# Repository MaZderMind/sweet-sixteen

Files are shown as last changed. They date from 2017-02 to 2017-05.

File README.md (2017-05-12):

# Sweet Sixteen
> a 16x2 Characters Sixten-Segment, RaspberryPi driven Display

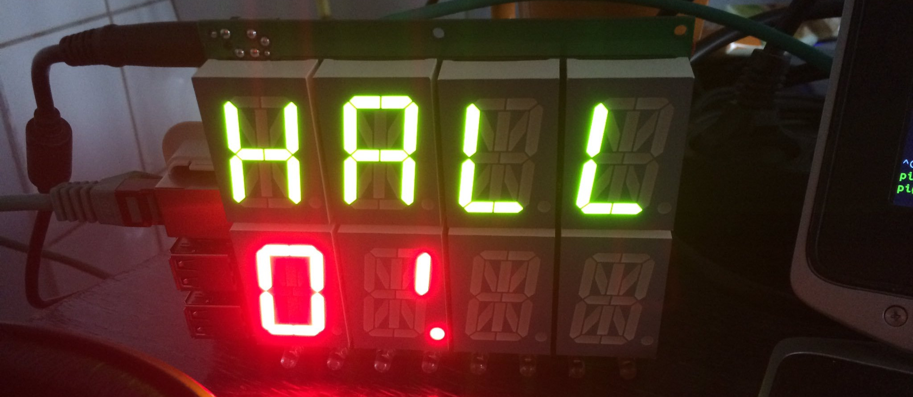
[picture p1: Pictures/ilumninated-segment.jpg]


## Quick Links
 * <a href="Hardware/Schematic.pdf">Schematic (PDF)</a>
 * <a href="Hardware/PCB-Layout.png">PCB Layout (Image)</a>
 * <a href="Hardware/BOM.ods">BOM</a>
 * <a href="Datasheets/">Datasheets</a>
 * <a href="https://github.com/MaZderMind/sweet-sixteen-scheduler">Software</a>

## System Design

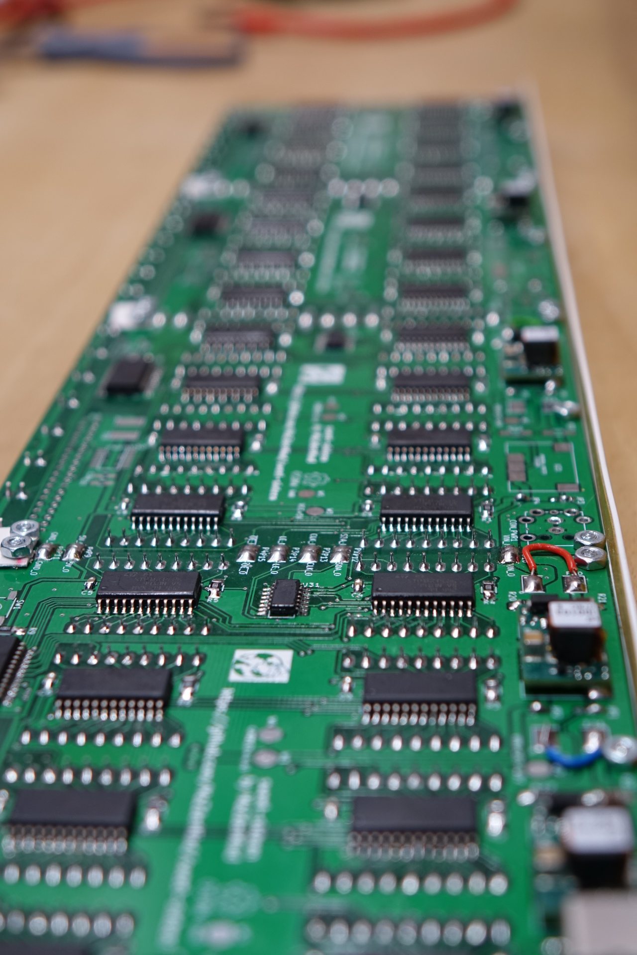
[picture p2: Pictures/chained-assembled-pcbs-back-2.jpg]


The System is built around [STP16CPC26](Datasheets/STP16CPC26.pdf) LED-Drivers in a direct drive configuration. Each LED-Driver has 16 Constant-Current sinks, each of which powers one Segment of the [PSA12-11](Datasheets/PSA12_11CGKWA.pdf) 16-Segment Displays.

The PCBs are built to be Chainable. The first Board in the Chain provides Data and the 5V Rail. It also carries the RaspberryPi "Piggy Back". The Board powers the Pi via its GPIO-Header, so there is no need to supply extra Power to the Pi (and you should not do that.)

## Signal Flow

The RaspberryPi generates Clock and Data via its Hardware-SPI Port (GPIO 10 & 11). Additionally it generates a Latch-Signal on GPIO 22 and an inverted Output-Enable Signal, which is can be used to Dim the LED-Drivers down, on one of its Hardware PWM Pins (GPIO 18).

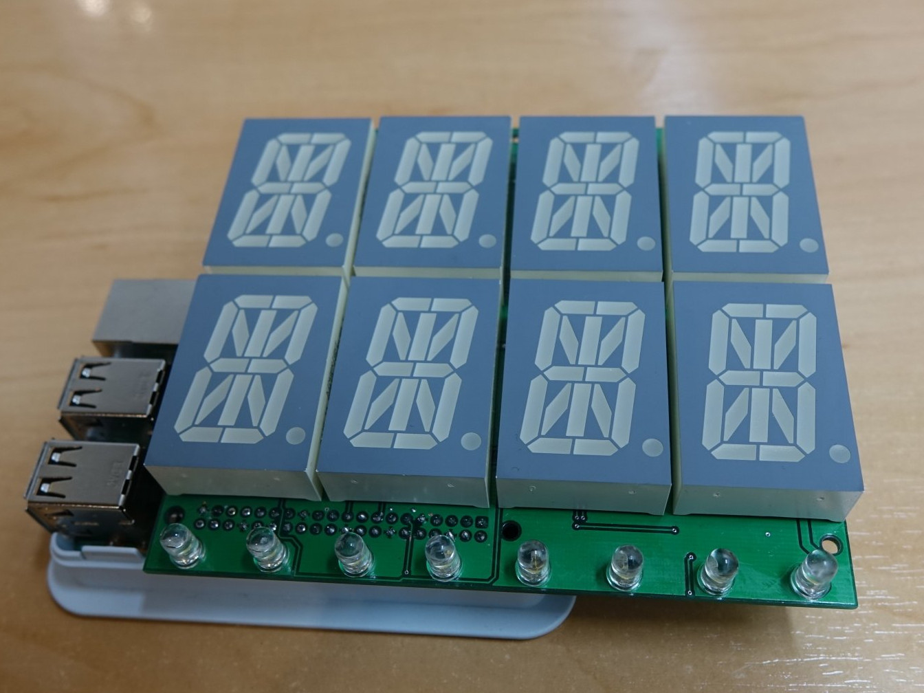
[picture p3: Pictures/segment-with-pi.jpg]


All of these Signals are 3.3V rated. They are directly fed into a [SN74HCT08](Datasheets/sn74hct08.pdf) and-gate which is used to convert the Signals to 5V compatible swing. These Signal then go on a parallel bus to all LED-Drivers (Clock, Latch and Output-Enable) resp. to the first LED-Driver (Data).

The LED-Drivers behave like Shift-Registers on the Data-Side, so the Data-Line ist chained from the input of one LED-Driver to the next, through all 9 Drivers. Drivers 1-8 each control one of the 16 Segments of one of the 8 Digits, while the 9th Driver controls the Decimal Points of all Digits as well as the Row of the 8 LEDs on the bottom of the PCB.

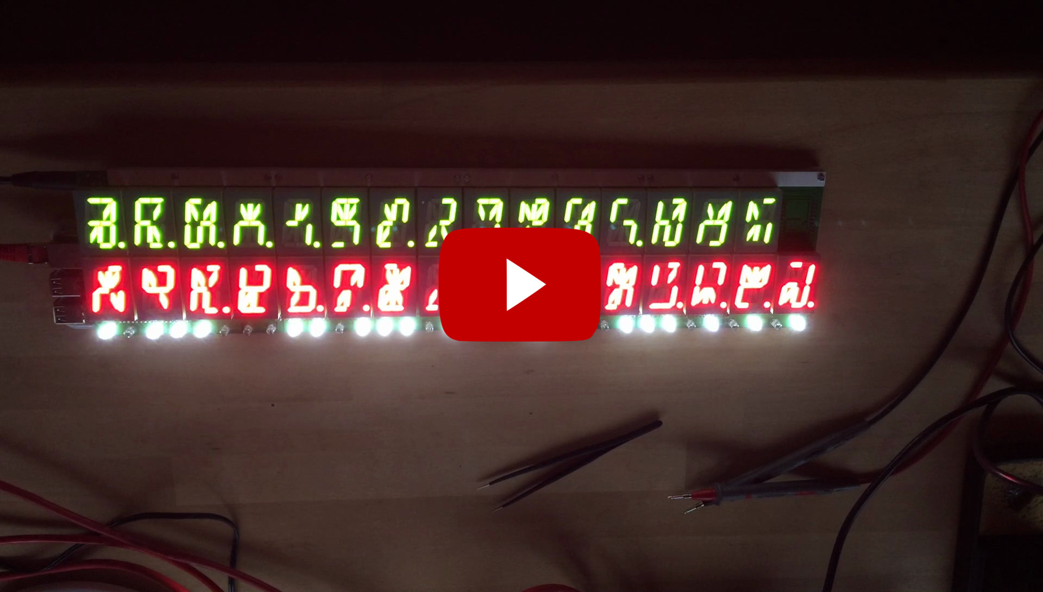
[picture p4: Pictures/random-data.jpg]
4 Boards displaying random Data


The Data-Output of the last LED-Driver as well as the paralleld Bus of Clock, Latch and Output Enable are fed to another [SN74HCT08](Datasheets/sn74hct08.pdf) and-gate which is here used as a line-driver to drive the LED-Drivers on the next PCB. After the and-gate the Signal is routed to Solder-Pads on the edge of the PCB which line up with matching Pads on the opposite Edge of the next PCB.

The Signals coming from those Pads feed into the next 9 LED-Drivers, just as the Raspberry-Pi did on the first PCB. The Components needed to interface to the Raspberry-Pi (Connectors, Fuse, and-Gate and some Caps) are not fitted on the following PCBs.

## Power System

The Whole System is Powered from a Notebook-Plugpack. I chose a Dell 19V/90W Plugpack because they are quite easy to get new or used on ebay for a small amount of money everywhere on the world. I terms of Power per Euro/Dollar Notebook-Chargers are unbeatable.

The 19V (actually the Input-Rail can range from 15V to 40V DC) is fed into two DC-DC Converter Modules on the first PCB, each of which is capable of generating up to 3A.

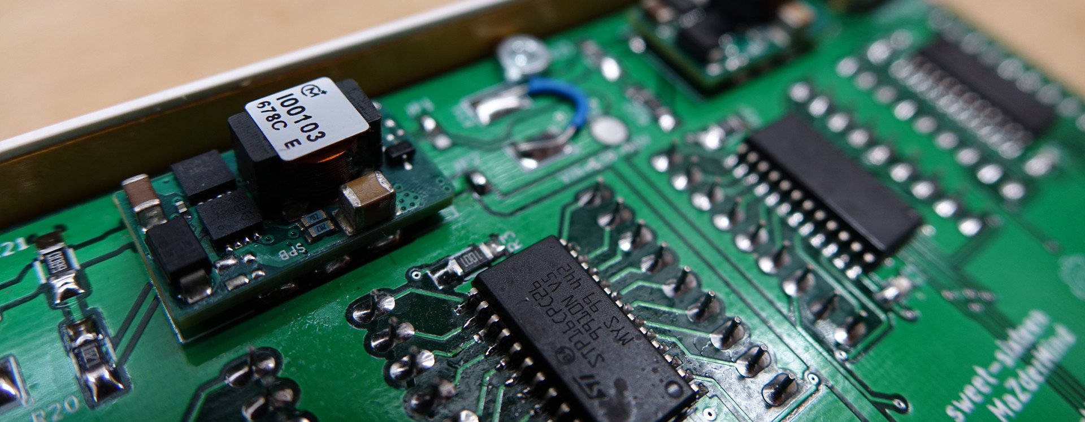
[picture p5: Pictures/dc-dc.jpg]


The first DC-DC Converter generates 5V and powers the RaspberryPi as well as as all the Logic-ICs on all PCBs.
The second Converter generates a 4.4V rail used to Power the LEDs – but this time only on the first PCB.

The following PCBs accept the 5V VCC Rail generated on the first PCB as well as the input-voltage from the Plugpack, also via Pads on the Edge of the PCBs. They are only fitted with the second DC-DC Converter and generate their own 4.4V VLED Rail for their LEDS.

When all LEDs ar on, the System draws about 45W or a little more, so 60W Dell Charger should also be okay. Take a look at the [Power Calculations](Hardware/Power%20Calculations.ods) to learn how the Current is consumed and which Temperature-Rise is to expect from the LED-Drivers.

## Software

The Software that runs the Display, pulls down the latest tweets, shows what the canteen has for Lunch, Blinks when a Software-Build fails or when it's a colleagues birthday grows over on [MaZderMind/sweet-sixteen-scheduler](https://github.com/MaZderMind/sweet-sixteen-scheduler).

## Build one yourself

To build your own you need
 * some PCBs
 * some Parts
 * a RaspberryPi
 * time, patience and tools to solder the SMD-Components (which is totally doable by Hand vith a good soldering Iron)

For the PCBs you can use the [pre-generated Gerbers](Gerbers/) but *be aware* that these are the Gerbers for rev1. I fixed some Bugs in rev1 but my Display uses rev0 boards and I have *not ordered or testet* the rev1 PCBs, though I'm quite sure they will work. If you want to play save, you can Download the rev0 Gerbers from the [rev0 Release-Page](https://github.com/MaZderMind/sweet-sixteen/releases/tag/rev0).

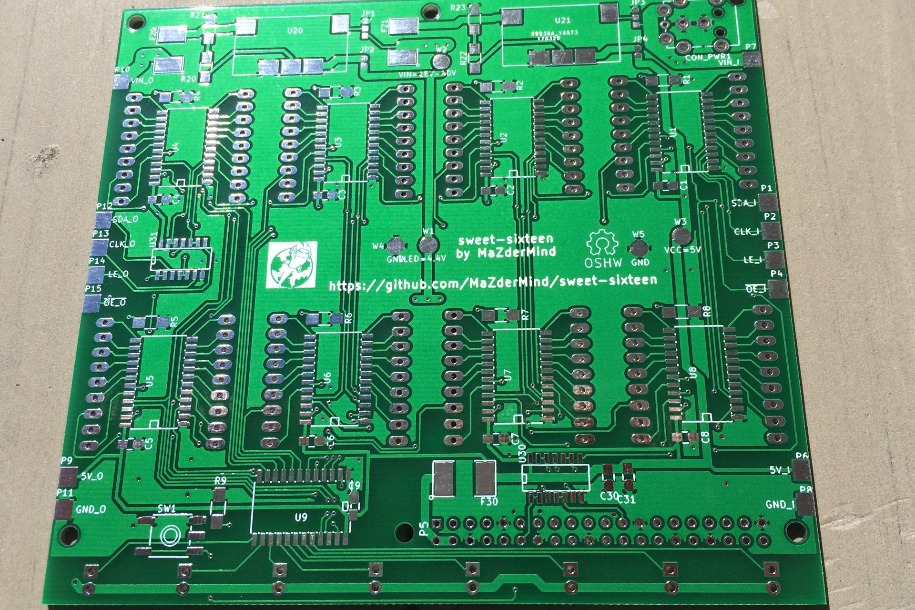
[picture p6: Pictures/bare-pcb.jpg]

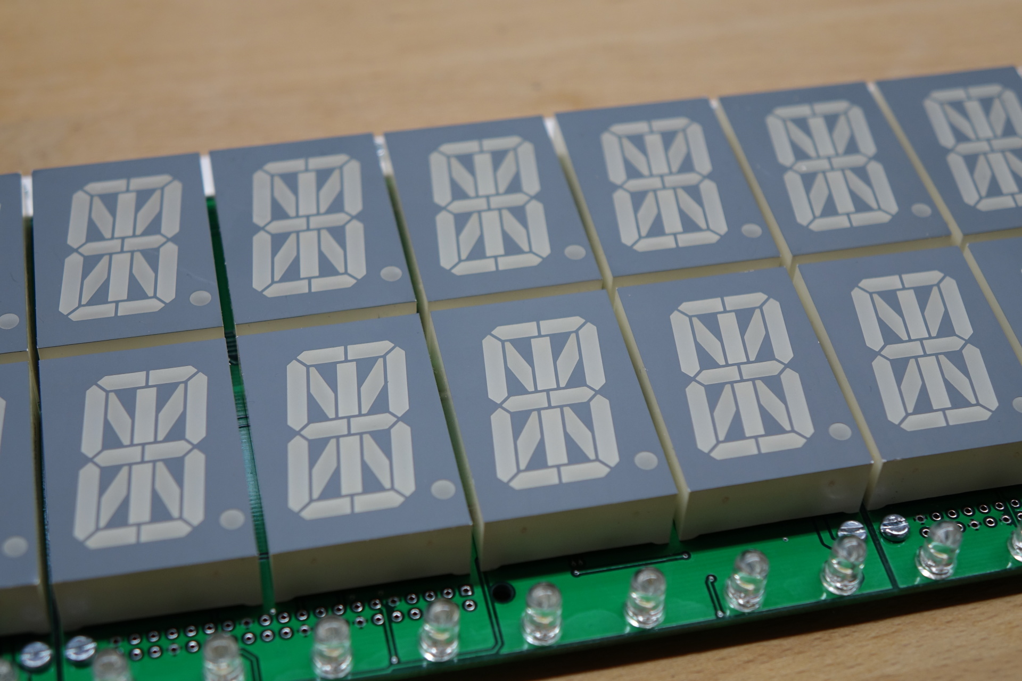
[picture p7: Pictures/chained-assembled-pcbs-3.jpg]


On the other Hand you might want to design in another Power-Connector, if you don't want to use Dell Plugpacks. The Schematics and PCBs are made with [KiCad](http://kicad-pcb.org/) which is Free Software and available on all Operating Systems. For the Parts please take a look at the [BOM](Hardware/BOM.ods) which contains all Parts I used.

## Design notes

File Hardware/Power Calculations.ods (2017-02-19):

Number of Double-LEDs per Digit
10
Number of Single-LEDs per Digit
6
Forward-Current |  | Forward-Voltage |  | Input-Voltage to Driver | Ground-Terminal Current |  |  | Thermal resistance junction-case
20.00 mA |  | 1.95 V | rot | 4.40 V | 320.00 mA | (max 1600 mA) |  | 60.00 °C\W
 |  | 2.10 V | grün
15.00 mA |  | 1.94 V
 |  | 2.06 V
10.00 mA |  | 1.94 V
 |  | 2.01 V
Voltage to use |  | Current to use |  |  | Per-Digit Current | 320.00 mA | @ 4.40 V
1.95 V |  | 20.00 mA |  |  | Per-Board Current | 2.56 A | @ 4.40 V
 |  |  |  |  | Total-System Current | 10.24 A | @ 4.40 V
Voltage Drop for Double-LEDs |  |  | Power Dissapation for Double-LEDs |  |  | 3.75 A | @ 12.00 V
0.50 V |  |  | 100.00 mW |  |  | 2.50 A | @ 18.00 V
 |  |  |  |  |  | 2.31 A | @ 19.50 V | (Notebook-Plugpack)
Voltage Drop for Single-LEDs |  |  | Power Dissapation for Single-LEDs
2.45 V |  |  | 294.00 mW
 |  |  |  |  | Total-System Power | 45.06 W
Minimum Total Power Dissapation
394.00 mW
Minimum Temperature Rise at Case above Ambient
23.64 °C | (53.64 °C)

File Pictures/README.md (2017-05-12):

# Sweet-Sixteen Media
More Images and Videos can be found at https://mazdermind.de/dl/sweet-sixteen-media/

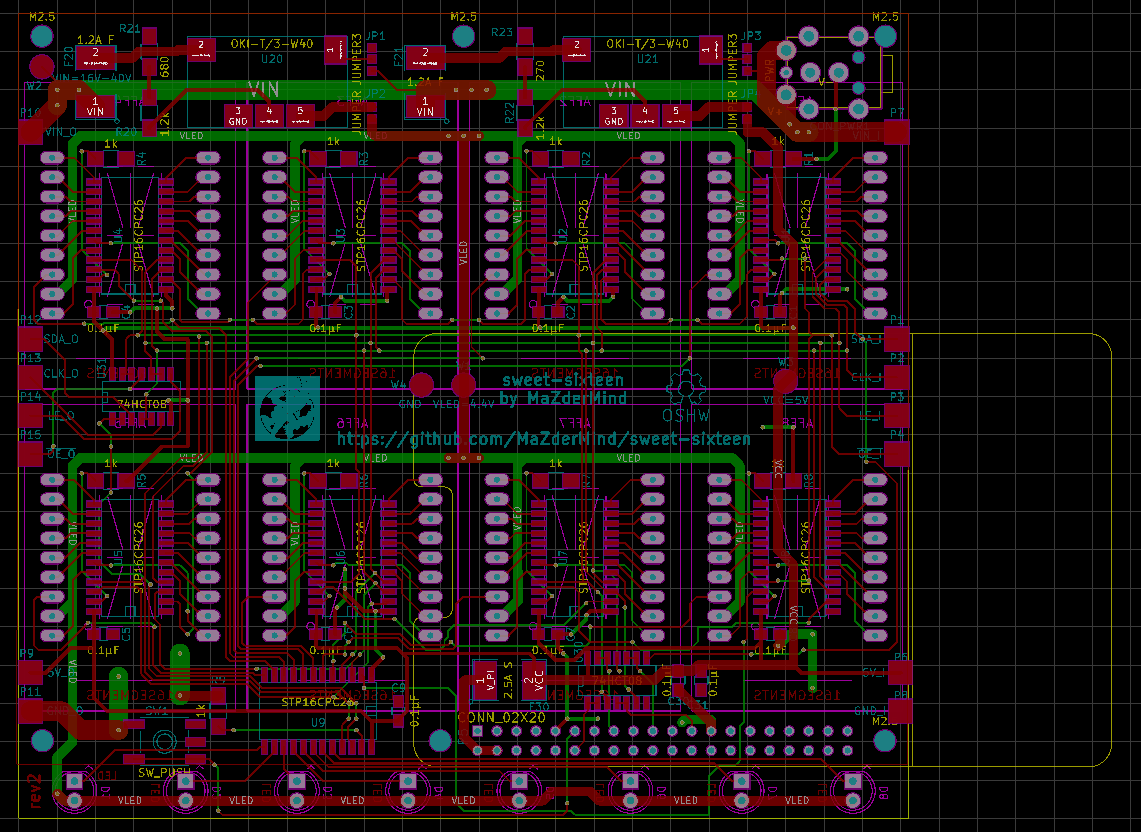
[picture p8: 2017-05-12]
Hardware/PCB-Layout.png

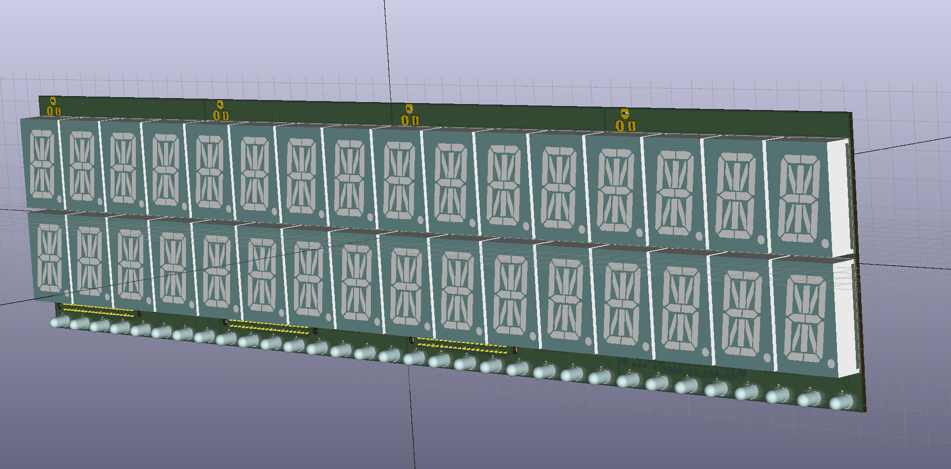
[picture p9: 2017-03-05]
3D-Renderings/sweet-sixteen-b-3d-chained.png

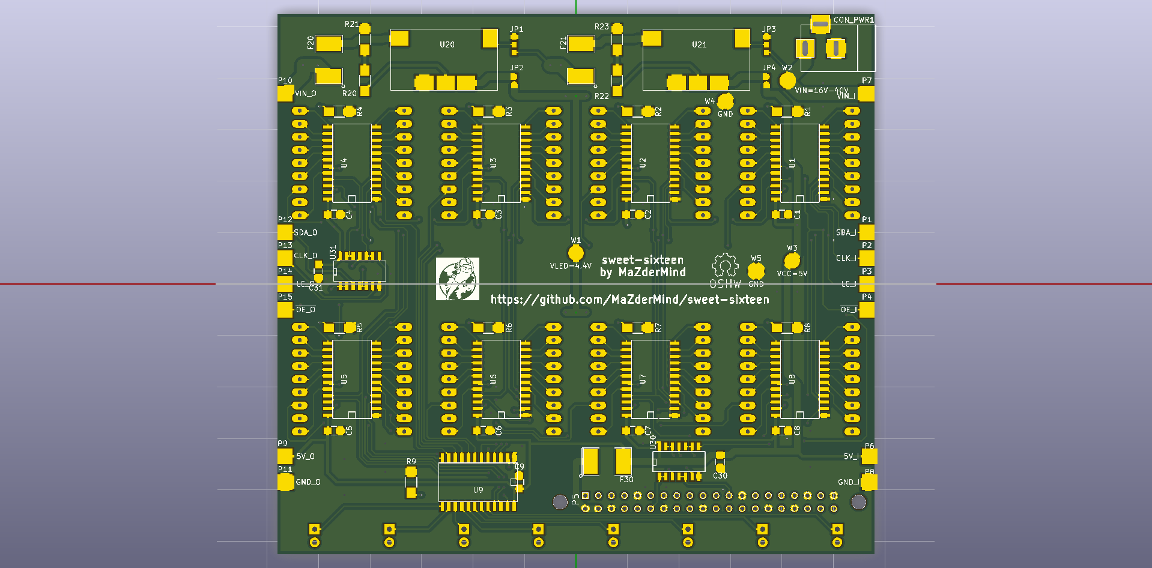
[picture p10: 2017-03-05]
3D-Renderings/sweet-sixteen-f.png

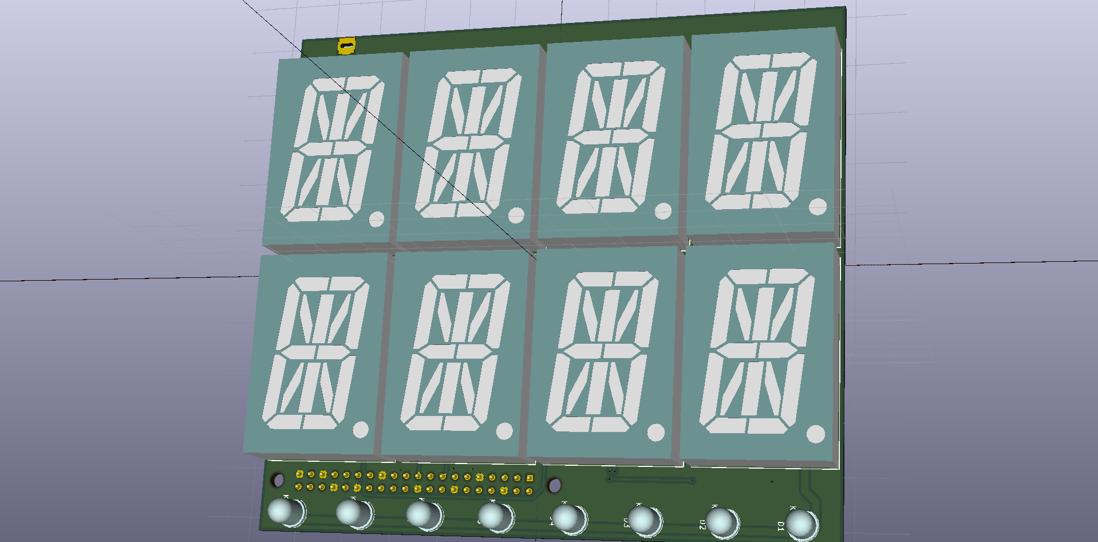
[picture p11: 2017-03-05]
3D-Renderings/sweet-sixteen-b-3d.png

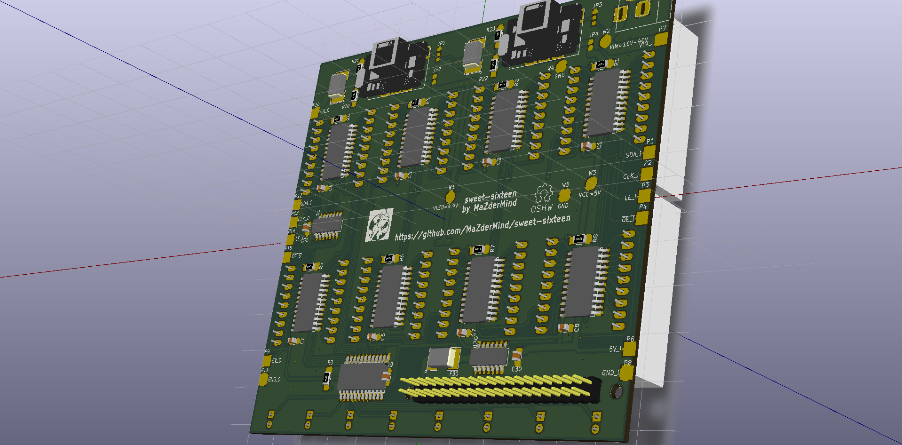
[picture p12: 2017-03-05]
3D-Renderings/sweet-sixteen-f-3d.png

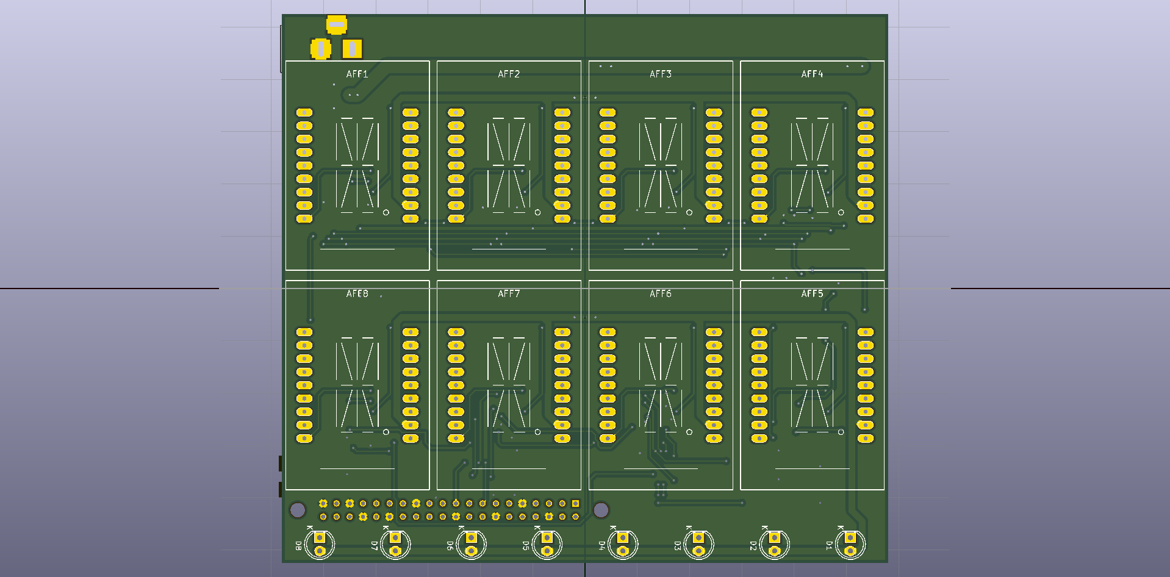
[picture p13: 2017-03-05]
3D-Renderings/sweet-sixteen-b.png

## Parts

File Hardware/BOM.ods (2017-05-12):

Manufacturer Part Nr. | Description | Qty* | Price | Total | URL
PSA12-11SURKWA | Displays Bottom (Red) | 16 | 3.29 € | 52.64 € | https://www.voelkner.de/products/660151/Kingbright-Alphanumerische-Segment-Anzeige-Rot-30.48-mm-3.7-V-Ziffernanzahl-1-PSA12-11SURKWA.html | Note: Alternative color Variants may be more readily available
PSA12-11CGKWA | Displays Top (Green) | 16 | 2.40 € | 38.40 € | https://www.voelkner.de/products/660153/Kingbright-Alphanumerische-Segment-Anzeige-Gruen-30.48-mm-4-V-Ziffernanzahl-1-PSA12-11CGKWA.html
STP16CPC26MTR | LED Driver | 36 | 0.96 € | 34.56 € | https://www.digikey.de/product-detail/de/stmicroelectronics/STP16CPC26MTR/497-11984-1-ND/2772289
SN74HCT08D | AND Gates as Level Shifter & Line Driver | 4 | 0.45 € | 1.80 € | https://www.digikey.de/product-detail/de/texas-instruments/SN74HCT08DR/296-14862-1-ND/562562
OKI-T/3-W40N-C | DC/DC Converter | 5 | 8.32 € | 41.60 € | https://www.digikey.de/product-detail/de/murata-power-solutions-inc/OKI-T-3-W40N-C/811-2152-1-ND/2182464
C503B-WAN-CBBDB231 | 3.2V 5mm Radial White LED | 32 | 0.20 € | 6.46 € | https://www.digikey.de/product-detail/de/cree-inc/C503B-WAN-CBBDB231/C503B-WAN-CBBDB231-ND/5824156
RC1206FR-07270RL | R 270 Ohm | 1 | 0.09 € | 0.09 € | https://www.digikey.de/product-detail/de/yageo/RC1206FR-07270RL/311-270FRCT-ND/731681
RC1206FR-07680RL | R 680 Ohm | 4 | 0.09 € | 0.36 € | https://www.digikey.de/product-detail/de/yageo/RC1206FR-07680RL/311-680FRCT-ND/732011
RC1206FR-071KL | R 1k Ohm | 36 | 0.09 € | 3.24 € | https://www.digikey.de/product-detail/de/yageo/RC1206FR-071KL/311-1.00KFRCT-ND/731334
RC1206FR-071K2L | R 1.2k Ohm | 5 | 0.09 € | 0.45 € | https://www.digikey.de/product-detail/de/yageo/RC1206FR-071K2L/311-1.20KFRCT-ND/731358
CL21B104KOANNNC | C 0.1uF | 37 | 0.09 € | 3.33 € | https://www.digikey.de/product-detail/de/samsung-electro-mechanics-america-inc/CL21B104KOANNNC/1276-2448-1-ND/3890534
CL21B105KPFNNNE | C 1uF | 1 | 0.09 € | 0.09 € | https://www.digikey.de/product-detail/de/samsung-electro-mechanics-america-inc/CL21B105KPFNNNE/1276-1275-1-ND/3889361
0679H1250-05 | F 1.25A / 20V+ | 4 | 0.31 | 1.24 € | https://www.digikey.de/product-detail/de/bel-fuse-inc/0679H1250-05/507-2047-1-ND/6139811
0679H2500-05 | F 2.5A / 20V+ | 1 | 0.31 | 0.31 € | https://www.digikey.de/product-detail/de/bel-fuse-inc/0679H2500-05/507-2050-1-ND/6139814
ADTSM61NVTR | Taster | 1 | 0.56 | 0.56 € | http://www.digikey.de/product-detail/de/apem-inc/ADTSM61NVTR/679-2380-1-ND/2344145
 | Dell Inspiron 1318 XPS Charging Port | 1 | 3.15 | 3.15 € | http://www.ebay.de/itm/Fur-Dell-Inspiron1318-XPS-M1330-DC-Power-Jack-Socket-OCTAGONAL-/201284646836 | Note: Other Power-Sources may be more convenient for you
 | Dell PlugPack | 1 | 12.95 | 12.95 € | http://www.ebay.de/itm/Original-Netzteil-fur-Dell-Latitude-Notebooks-19-5V-4-62A-90W-PA-10-Family-/152527912081
 |  |  |  | 148.59 €
 |  | 4 | *) Configure number of Boards here

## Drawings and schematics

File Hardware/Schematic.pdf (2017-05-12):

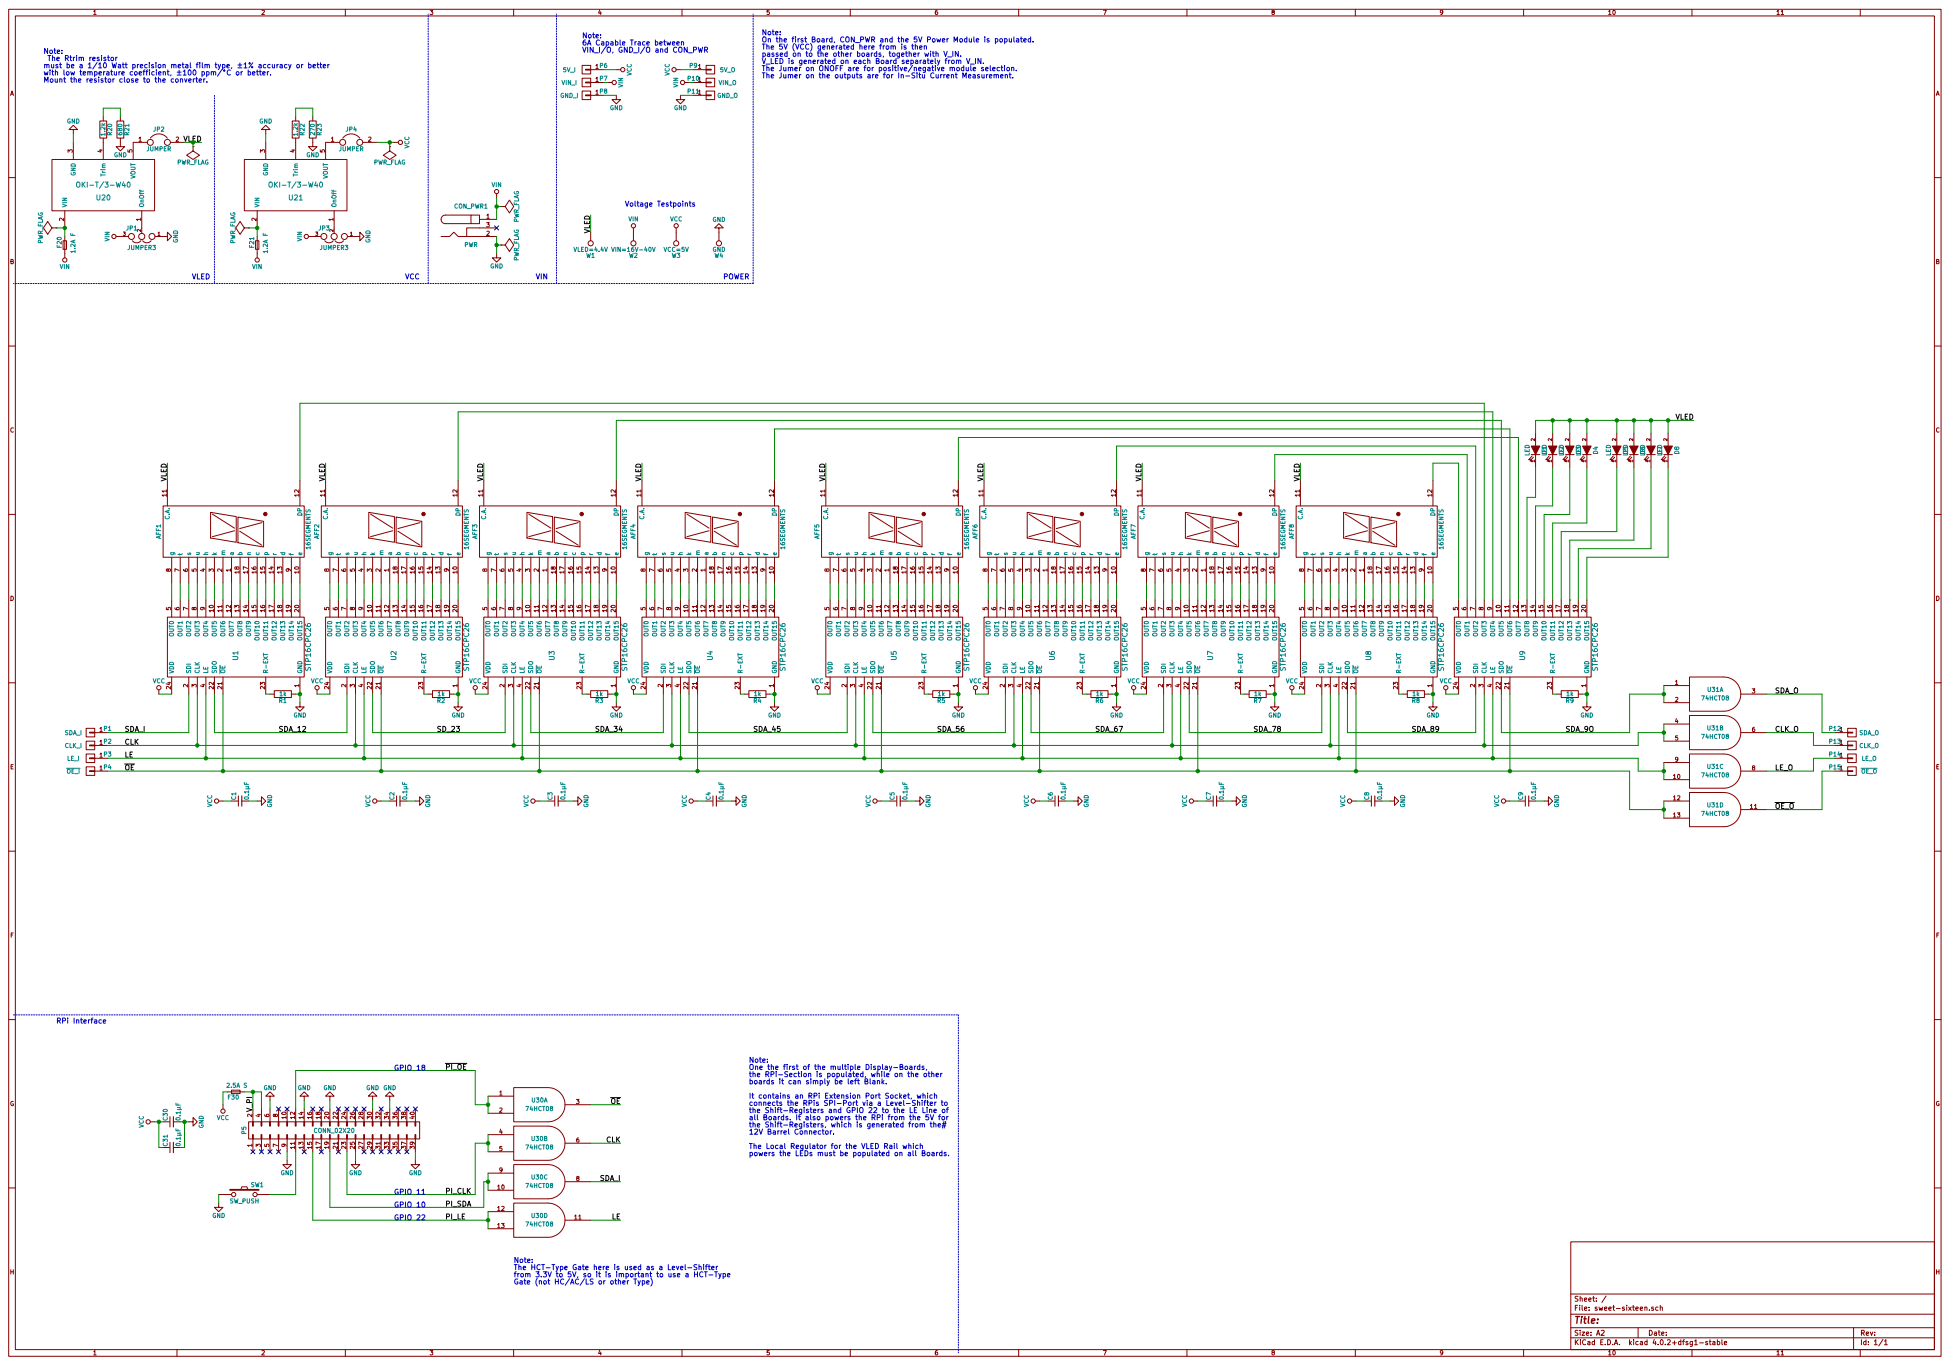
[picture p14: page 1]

Note: 6A Capable Trace between

Note: On the first Board, CON_PWR and the 5V Power Module is populated.
The 5V (VCC) generated here from is then
passed on to the other boards, together with V_IN.
V_LED is generated on each Board separately from V_IN.

JUMPER3 Note:
The Rtrim resistor must be a 1/10 Watt precision metal film type, ±1% accuracy or better
with low temperature coefficient, ±100 ppm/°C or better. Mount the resistor close to the converter.

The Jumer on ONOFF are for positive/negative module selection.
The Jumer on the outputs are for In-Situ Current Measurement.

Gate (not HC/AC/LS or other Type) OnOff 1 VIN

9 OUT5 10 OUT15 20 OUT6 11 OE 21 OUT7 12 SDO 22 OUT8 13 R-EXT 23 OUT9 14 VDD 24 OUT10 15 OUT11 16 OUT12 17 OUT13 18 OUT14 19 U1 STP16CPC26 GND

9 OUT5 10 OUT15 20 OUT6 11 OE 21 OUT7 12 SDO 22 OUT8 13 R-EXT 23 OUT9 14 VDD 24 OUT10 15 OUT11 16 OUT12 17 OUT13 18 OUT14 19 U2 STP16CPC26 GND

9 OUT5 10 OUT15 20 OUT6 11 OE 21 OUT7 12 SDO 22 OUT8 13 R-EXT 23 OUT9 14 VDD 24 OUT10 15 OUT11 16 OUT12 17 OUT13 18 OUT14 19 U3 STP16CPC26 GND

9 OUT5 10 OUT15 20 OUT6 11 OE 21 OUT7 12 SDO 22 OUT8 13 R-EXT 23 OUT9 14 VDD 24 OUT10 15 OUT11 16 OUT12 17 OUT13 18 OUT14 19 U4 STP16CPC26 GND

9 OUT5 10 OUT15 20 OUT6 11 OE 21 OUT7 12 SDO 22 OUT8 13 R-EXT 23 OUT9 14 VDD 24 OUT10 15 OUT11 16 OUT12 17 OUT13 18 OUT14 19 U5 STP16CPC26

9 OUT5 10 OUT15 20 OUT6 11 OE 21 OUT7 12 SDO 22 OUT8 13 R-EXT 23 OUT9 14 VDD 24 OUT10 15 OUT11 16 OUT12 17 OUT13 18 OUT14 19 U6 STP16CPC26 GND

9 OUT5 10 OUT15 20 OUT6 11 OE 21 OUT7 12 SDO 22 OUT8 13 R-EXT 23 OUT9 14 VDD 24 OUT10 15 OUT11 16 OUT12 17 OUT13 18 OUT14 19 U7 STP16CPC26 GND

9 OUT5 10 OUT15 20 OUT6 11 OE 21 OUT7 12 SDO 22 OUT8 13 R-EXT 23 OUT9 14 VDD 24 OUT10 15 OUT11 16 OUT12 17 OUT13 18 OUT14 19 U8 STP16CPC26

9 OUT5 10 OUT15 20 OUT6 11 OE 21 OUT7 12 SDO 22 OUT8 13 R-EXT 23 OUT9 14 VDD 24 OUT10 15 OUT11 16 OUT12 17 OUT13 18 OUT14 19 U9 STP16CPC26

74HCT08 Note: The HCT-Type Gate here is used as a Level-Shifter

the RPi-Section is populated, while on the other
boards it can simply be left Blank.
It contains an RPi Extension Port Socket, which
connects the RPis SPI-Port via a Level-Shifter to
the Shift-Registers and GPIO 22 to the LE Line of
all Boards. It also powers the RPi from the 5V for
the Shift-Registers, which is generated from the#
12V Barrel Connector.
The Local Regulator for the VLED Rail which

9 10203040 112131 122232 132333 142434 152535 162636 172737 182838 192939 P5CONN_02X20 GND GND GND GND GND GND V_PI

powers the LEDs must be populated on all Boards. 8

from 3.3V to 5V, so it is important to use a HCT-Type

Id: 1/1 Title: File: sweet-sixteen.sch Sheet: /

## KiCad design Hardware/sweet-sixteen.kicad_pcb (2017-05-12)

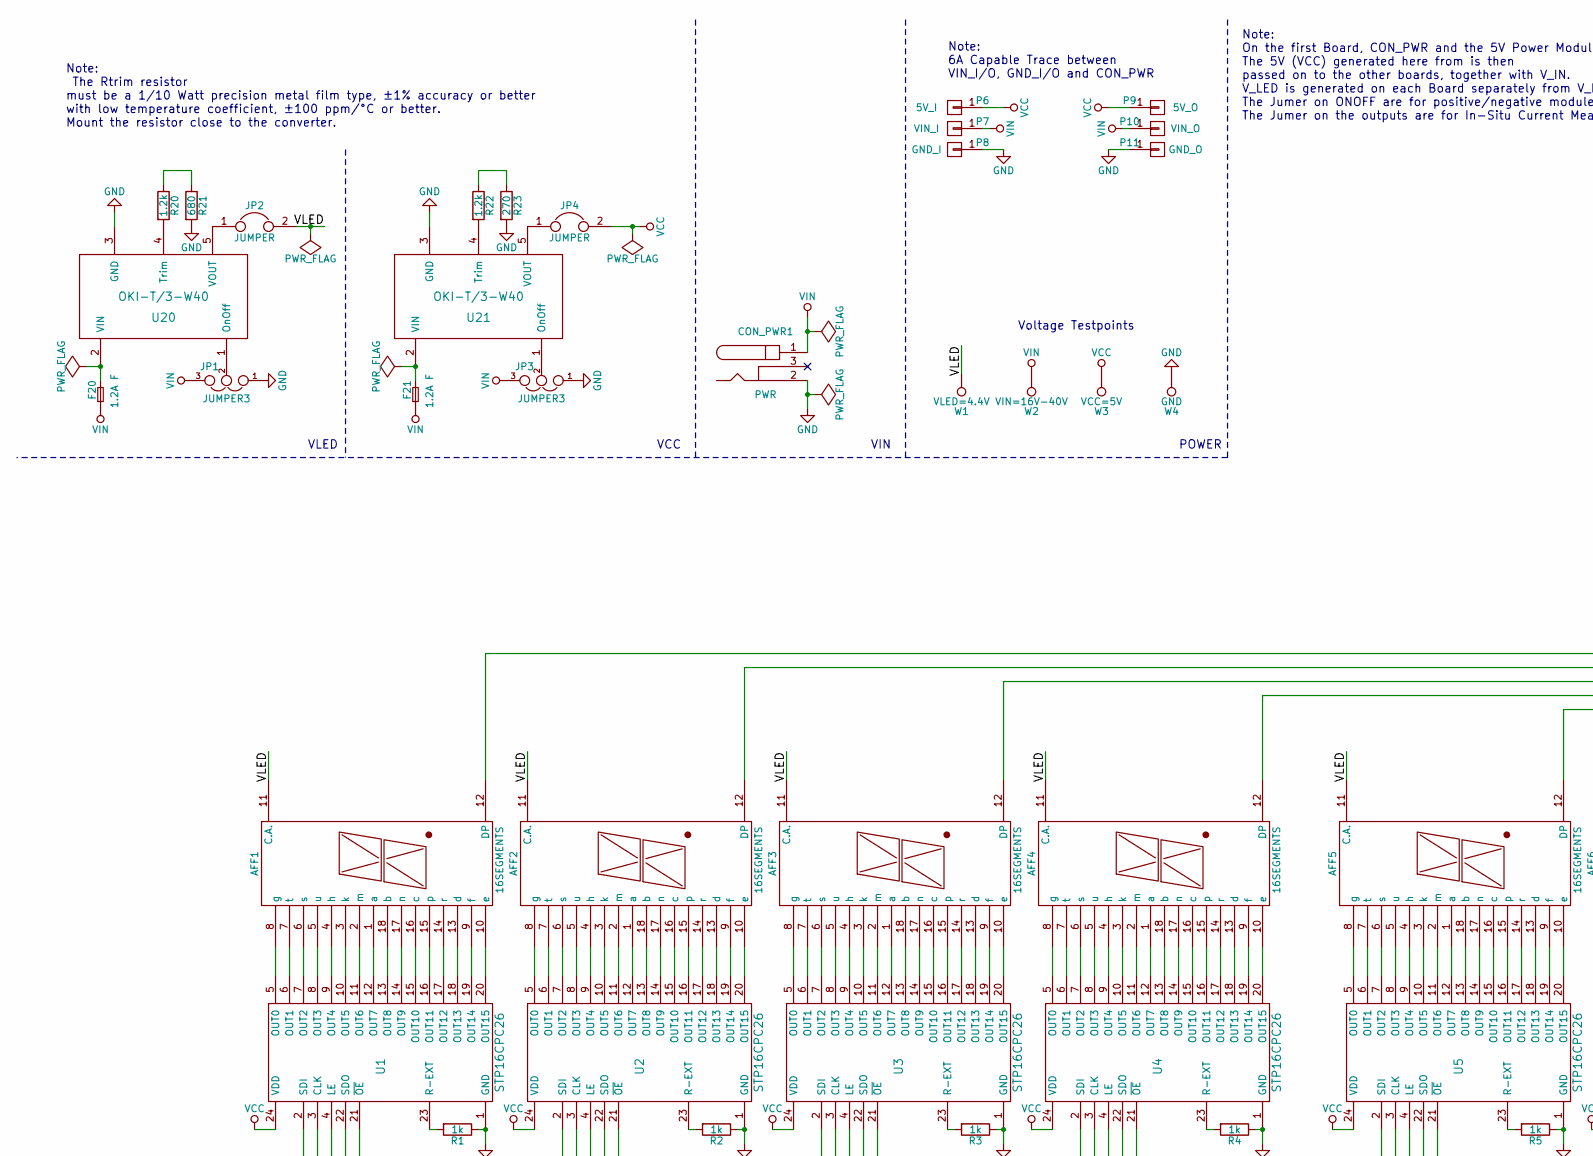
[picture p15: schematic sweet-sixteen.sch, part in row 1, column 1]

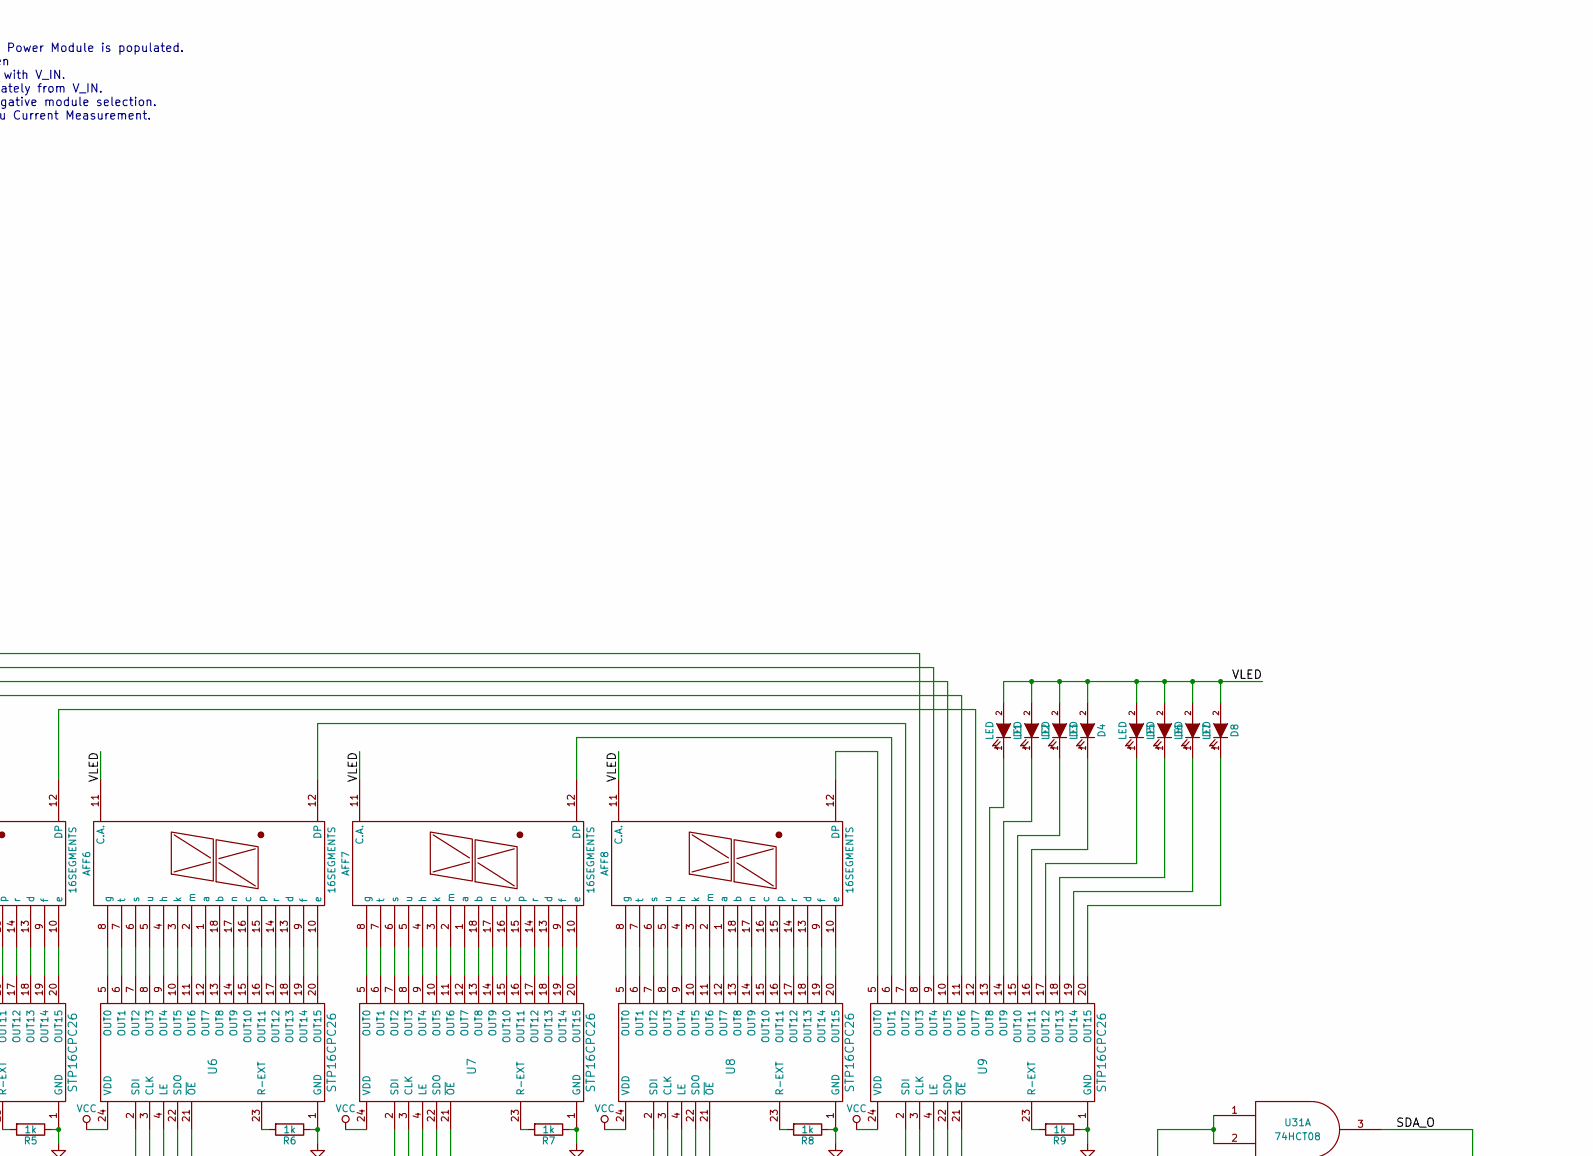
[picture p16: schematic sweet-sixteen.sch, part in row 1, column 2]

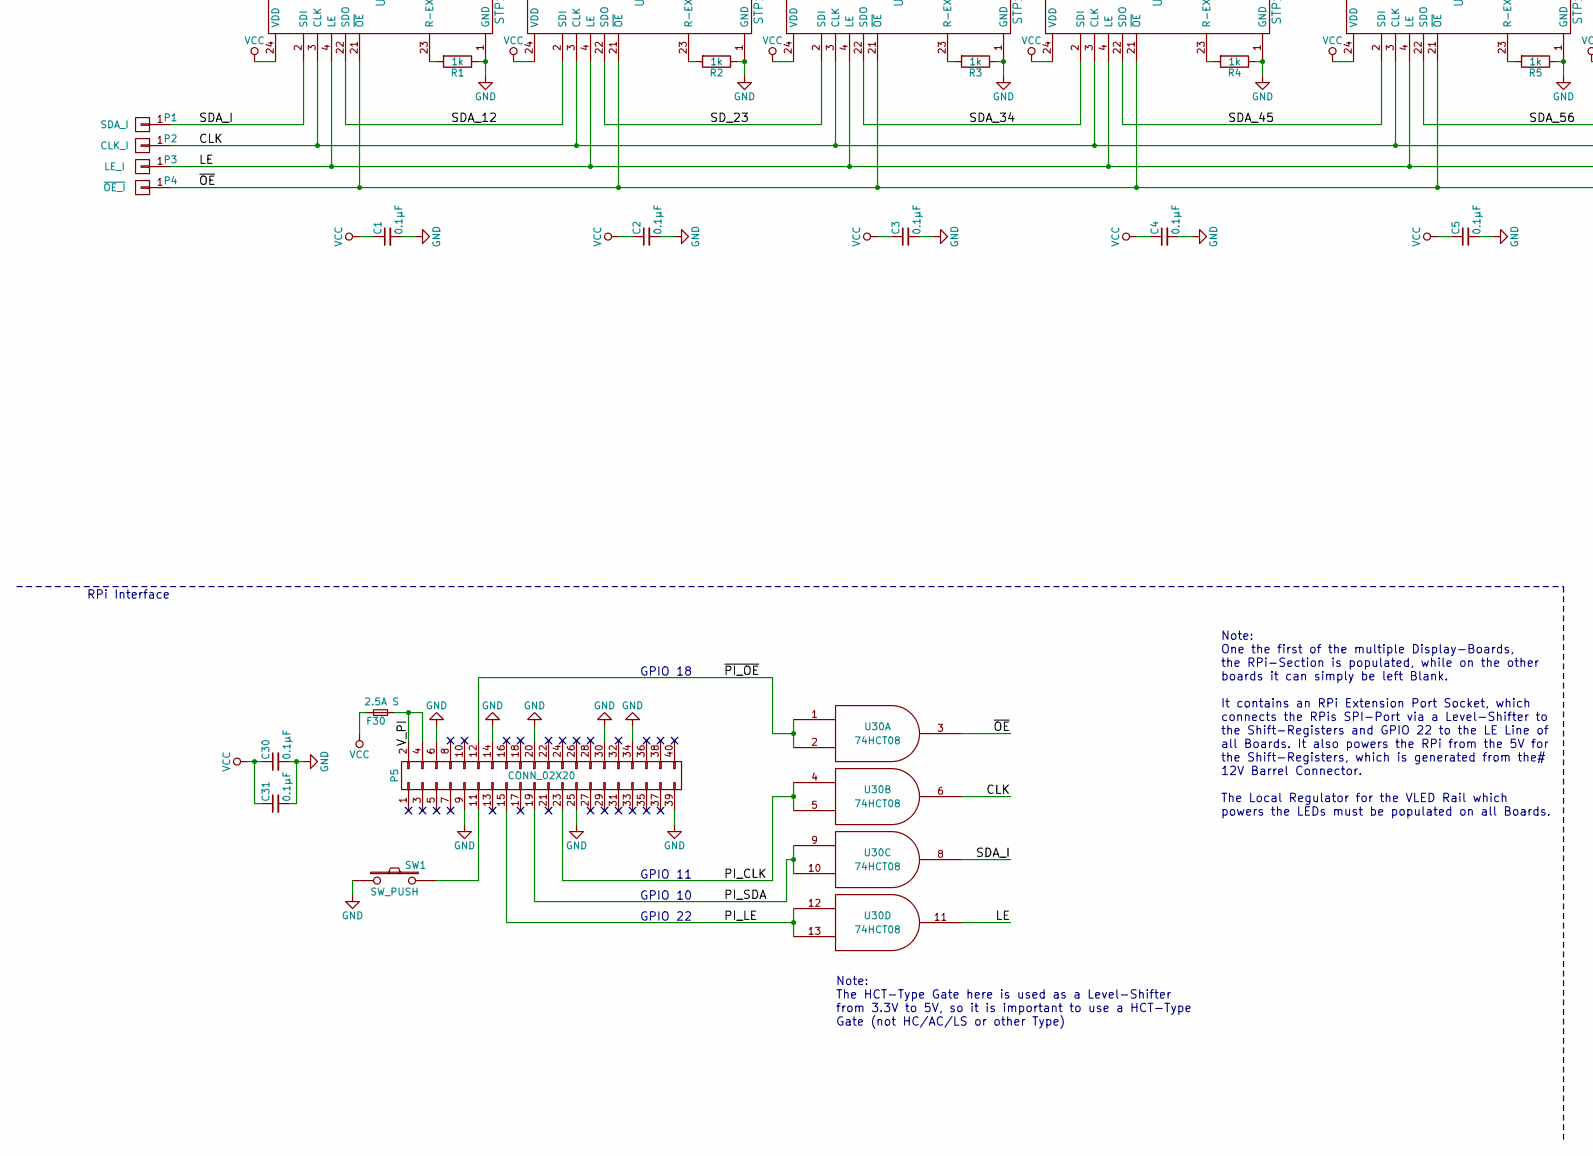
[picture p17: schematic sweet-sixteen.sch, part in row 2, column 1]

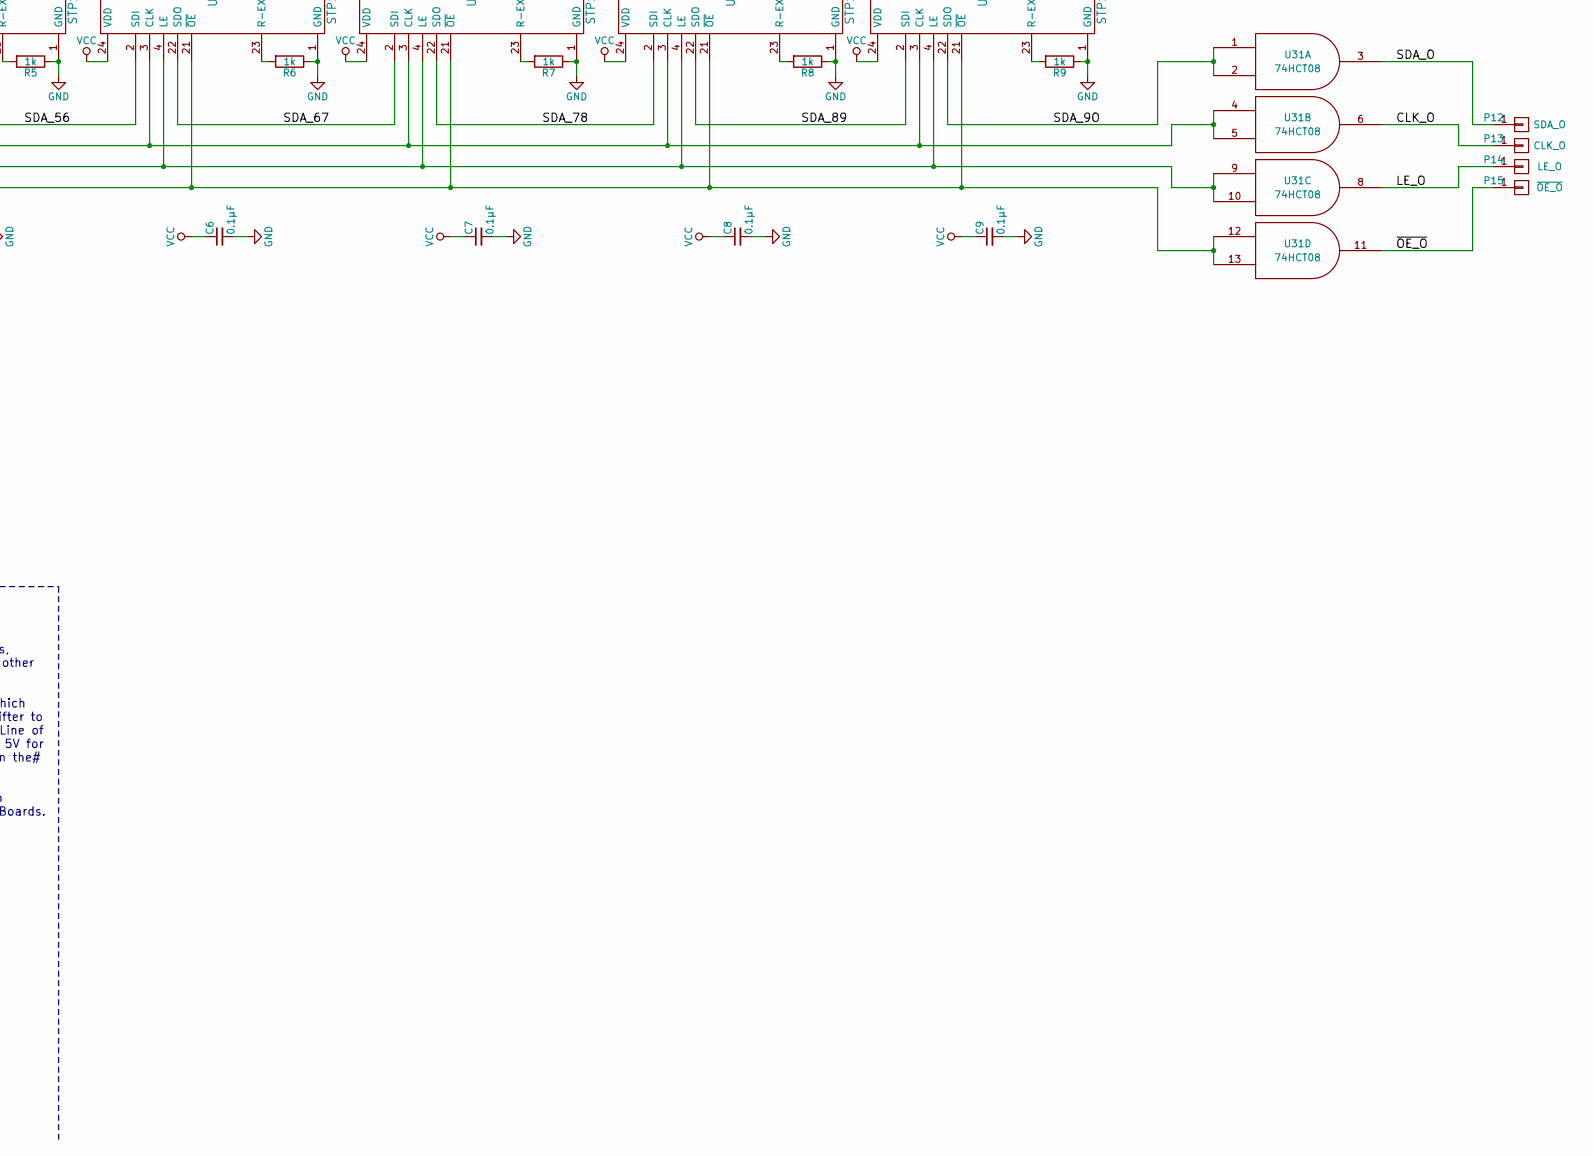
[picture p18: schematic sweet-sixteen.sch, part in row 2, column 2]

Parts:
AFF1, AFF2, AFF3, AFF4, AFF5, AFF6, AFF7, AFF8: 16SEGMENTS; PSA12-11
C1, C2, C3, C4, C5, C6, C7, C8, C9, C30, C31: 0.1μF; C_0805_HandSoldering
CON_PWR1: PWR; DELL-PCON
D1, D2, D3, D4, D5, D6, D7, D8: LED; LED-5MM
F20, F21: 1.2A F; SMD-2112_Pol
F30: 2.5A S; SMD-2112_Pol
JP1, JP3: JUMPER3; SMD_Jumper_3
JP2, JP4: JUMPER; SMD_Jumper_2
P1: SDA_I; Measurement_Point_Square-SMD-Pad_Big
P2: CLK_I; Measurement_Point_Square-SMD-Pad_Big
P3: LE_I; Measurement_Point_Square-SMD-Pad_Big
P4: ~OE_I; Measurement_Point_Square-SMD-Pad_Big
P5: CONN_02X20; rpi-header
P6: 5V_I; Measurement_Point_Square-SMD-Pad_Big
P7: VIN_I; Measurement_Point_Square-SMD-Pad_Big
P8: GND_I; Measurement_Point_Square-SMD-Pad_Big
P9: 5V_O; Measurement_Point_Square-SMD-Pad_Big
P10: VIN_O; Measurement_Point_Square-SMD-Pad_Big
P11: GND_O; Measurement_Point_Square-SMD-Pad_Big
P12: SDA_O; Measurement_Point_Square-SMD-Pad_Big
P13: CLK_O; Measurement_Point_Square-SMD-Pad_Big
P14: LE_O; Measurement_Point_Square-SMD-Pad_Big
P15: ~OE_O; Measurement_Point_Square-SMD-Pad_Big
R1, R2, R3, R4, R5, R6, R7, R8, R9: 1k; R_1206_HandSoldering
R20, R22: 1.2k; R_1206_HandSoldering
R21: 680; R_1206_HandSoldering
R23: 270; R_1206_HandSoldering
SW1: SW_PUSH; ADTSM61
U1, U2, U3, U4, U5, U6, U7, U8, U9: STP16CPC26; STP16CPC26MTR
U20, U21: OKI-T/3-W40; OKI-T3
U30, U31: 74HCT08; SN74HCT08D
W1: VLED=4.4V; Measurement_Point_Round-SMD-Pad_Big
W2: VIN=16V-40V; Measurement_Point_Round-SMD-Pad_Big
W3: VCC=5V; Measurement_Point_Round-SMD-Pad_Big
W4: GND; Measurement_Point_Round-SMD-Pad_Big

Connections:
/CLK: P2.1, U1.3 (CLK), U2.3 (CLK), U3.3 (CLK), U4.3 (CLK), U5.3 (CLK), U6.3 (CLK), U7.3 (CLK), U8.3 (CLK), U9.3 (CLK), U30.6, U31.4, U31.5
/CLK_O: P13.1, U31.6
/LE: P3.1, U1.4 (LE), U2.4 (LE), U3.4 (LE), U4.4 (LE), U5.4 (LE), U6.4 (LE), U7.4 (LE), U8.4 (LE), U9.4 (LE), U30.11, U31.9, U31.10
/LE_O: P14.1, U31.8
/PI_CLK: P5.23, U30.4, U30.5
/PI_LE: P5.15, U30.12, U30.13
/PI_SDA: P5.19, U30.9, U30.10
/SDA_9O: U9.22 (SDO), U31.1, U31.2
/SDA_12: U1.22 (SDO), U2.2 (SDI)
/SDA_34: U3.22 (SDO), U4.2 (SDI)
/SDA_45: U4.22 (SDO), U5.2 (SDI)
/SDA_56: U5.22 (SDO), U6.2 (SDI)
/SDA_67: U6.22 (SDO), U7.2 (SDI)
/SDA_78: U7.22 (SDO), U8.2 (SDI)
/SDA_89: U8.22 (SDO), U9.2 (SDI)
/SDA_I: P1.1, U1.2 (SDI), U30.8
/SDA_O: P12.1, U31.3
/SD_23: U2.22 (SDO), U3.2 (SDI)
/VLED: AFF1.11 (C.A.), AFF2.11 (C.A.), AFF3.11 (C.A.), AFF4.11 (C.A.), AFF5.11 (C.A.), AFF6.11 (C.A.), AFF7.11 (C.A.), AFF8.11 (C.A.), D1.2 (A), D2.2 (A), D3.2 (A), D4.2 (A), D5.2 (A), D6.2 (A), D7.2 (A), D8.2 (A), JP2.2, W1.1
/V_PI: F30.1, P5.2, P5.4
/~OE: P4.1, U1.21 (~OE), U2.21 (~OE), U3.21 (~OE), U4.21 (~OE), U5.21 (~OE), U6.21 (~OE), U7.21 (~OE), U8.21 (~OE), U9.21 (~OE), U30.3, U31.12, U31.13
/~OE_O: P15.1, U31.11
/~PI_OE: P5.12, U30.1, U30.2
GND: C1.2, C2.2, C3.2, C4.2, C5.2, C6.2, C7.2, C8.2, C9.2, C30.2, C31.2, CON_PWR1.2, JP1.1, JP3.1, P5.6, P5.9, P5.14, P5.20, P5.25, P5.30, P5.34, P5.39, P8.1, P11.1, R1.1, R2.1, R3.1, R4.1, R5.1, R6.1, R7.1, R8.1, R9.1, R21.2, R23.2, SW1.1, U1.1 (GND), U2.1 (GND), U3.1 (GND), U4.1 (GND), U5.1 (GND), U6.1 (GND), U7.1 (GND), U8.1 (GND), U9.1 (GND), U20.3 (GND), U21.3 (GND), U30.7 (GND), U31.7 (GND), W4.1
unnamed: AFF1.1 (a), U1.12 (OUT7)
unnamed: AFF1.2 (m), U1.11 (OUT6)
unnamed: AFF1.3 (k), U1.10 (OUT5)
unnamed: AFF1.4 (h), U1.9 (OUT4)
unnamed: AFF1.5 (u), U1.8 (OUT3)
unnamed: AFF1.6 (s), U1.7 (OUT2)
unnamed: AFF1.7 (t), U1.6 (OUT1)
unnamed: AFF1.8 (g), U1.5 (OUT0)
unnamed: AFF1.9 (f), U1.19 (OUT14)
unnamed: AFF1.10 (e), U1.20 (OUT15)
unnamed: AFF1.12 (DP), U9.8 (OUT3)
unnamed: AFF1.13 (d), U1.18 (OUT13)
unnamed: AFF1.14 (r), U1.17 (OUT12)
unnamed: AFF1.15 (p), U1.16 (OUT11)
unnamed: AFF1.16 (c), U1.15 (OUT10)
unnamed: AFF1.17 (n), U1.14 (OUT9)
unnamed: AFF1.18 (b), U1.13 (OUT8)
unnamed: AFF2.1 (a), U2.12 (OUT7)
unnamed: AFF2.2 (m), U2.11 (OUT6)
unnamed: AFF2.3 (k), U2.10 (OUT5)
unnamed: AFF2.4 (h), U2.9 (OUT4)
unnamed: AFF2.5 (u), U2.8 (OUT3)
unnamed: AFF2.6 (s), U2.7 (OUT2)
unnamed: AFF2.7 (t), U2.6 (OUT1)
unnamed: AFF2.8 (g), U2.5 (OUT0)
unnamed: AFF2.9 (f), U2.19 (OUT14)
unnamed: AFF2.10 (e), U2.20 (OUT15)
unnamed: AFF2.12 (DP), U9.9 (OUT4)
unnamed: AFF2.13 (d), U2.18 (OUT13)
unnamed: AFF2.14 (r), U2.17 (OUT12)
unnamed: AFF2.15 (p), U2.16 (OUT11)
unnamed: AFF2.16 (c), U2.15 (OUT10)
unnamed: AFF2.17 (n), U2.14 (OUT9)
unnamed: AFF2.18 (b), U2.13 (OUT8)
unnamed: AFF3.1 (a), U3.12 (OUT7)
unnamed: AFF3.2 (m), U3.11 (OUT6)
unnamed: AFF3.3 (k), U3.10 (OUT5)
unnamed: AFF3.4 (h), U3.9 (OUT4)
unnamed: AFF3.5 (u), U3.8 (OUT3)
unnamed: AFF3.6 (s), U3.7 (OUT2)
unnamed: AFF3.7 (t), U3.6 (OUT1)
unnamed: AFF3.8 (g), U3.5 (OUT0)
unnamed: AFF3.9 (f), U3.19 (OUT14)
unnamed: AFF3.10 (e), U3.20 (OUT15)
unnamed: AFF3.12 (DP), U9.10 (OUT5)
unnamed: AFF3.13 (d), U3.18 (OUT13)
unnamed: AFF3.14 (r), U3.17 (OUT12)
unnamed: AFF3.15 (p), U3.16 (OUT11)
unnamed: AFF3.16 (c), U3.15 (OUT10)
unnamed: AFF3.17 (n), U3.14 (OUT9)
unnamed: AFF3.18 (b), U3.13 (OUT8)
unnamed: AFF4.1 (a), U4.12 (OUT7)
unnamed: AFF4.2 (m), U4.11 (OUT6)
unnamed: AFF4.3 (k), U4.10 (OUT5)
unnamed: AFF4.4 (h), U4.9 (OUT4)
unnamed: AFF4.5 (u), U4.8 (OUT3)
unnamed: AFF4.6 (s), U4.7 (OUT2)
unnamed: AFF4.7 (t), U4.6 (OUT1)
unnamed: AFF4.8 (g), U4.5 (OUT0)
unnamed: AFF4.9 (f), U4.19 (OUT14)
unnamed: AFF4.10 (e), U4.20 (OUT15)
unnamed: AFF4.12 (DP), U9.11 (OUT6)
unnamed: AFF4.13 (d), U4.18 (OUT13)
unnamed: AFF4.14 (r), U4.17 (OUT12)
unnamed: AFF4.15 (p), U4.16 (OUT11)
unnamed: AFF4.16 (c), U4.15 (OUT10)
unnamed: AFF4.17 (n), U4.14 (OUT9)
unnamed: AFF4.18 (b), U4.13 (OUT8)
unnamed: AFF5.1 (a), U5.12 (OUT7)
unnamed: AFF5.2 (m), U5.11 (OUT6)
unnamed: AFF5.3 (k), U5.10 (OUT5)
unnamed: AFF5.4 (h), U5.9 (OUT4)
unnamed: AFF5.5 (u), U5.8 (OUT3)
unnamed: AFF5.6 (s), U5.7 (OUT2)
unnamed: AFF5.7 (t), U5.6 (OUT1)
unnamed: AFF5.8 (g), U5.5 (OUT0)
unnamed: AFF5.9 (f), U5.19 (OUT14)
unnamed: AFF5.10 (e), U5.20 (OUT15)
unnamed: AFF5.12 (DP), U9.12 (OUT7)
unnamed: AFF5.13 (d), U5.18 (OUT13)
unnamed: AFF5.14 (r), U5.17 (OUT12)
unnamed: AFF5.15 (p), U5.16 (OUT11)
unnamed: AFF5.16 (c), U5.15 (OUT10)
unnamed: AFF5.17 (n), U5.14 (OUT9)
unnamed: AFF5.18 (b), U5.13 (OUT8)
unnamed: AFF6.1 (a), U6.12 (OUT7)
unnamed: AFF6.2 (m), U6.11 (OUT6)
unnamed: AFF6.3 (k), U6.10 (OUT5)
unnamed: AFF6.4 (h), U6.9 (OUT4)
unnamed: AFF6.5 (u), U6.8 (OUT3)
unnamed: AFF6.6 (s), U6.7 (OUT2)
unnamed: AFF6.7 (t), U6.6 (OUT1)
unnamed: AFF6.8 (g), U6.5 (OUT0)
unnamed: AFF6.9 (f), U6.19 (OUT14)
unnamed: AFF6.10 (e), U6.20 (OUT15)
unnamed: AFF6.12 (DP), U9.7 (OUT2)
unnamed: AFF6.13 (d), U6.18 (OUT13)
unnamed: AFF6.14 (r), U6.17 (OUT12)
unnamed: AFF6.15 (p), U6.16 (OUT11)
unnamed: AFF6.16 (c), U6.15 (OUT10)
unnamed: AFF6.17 (n), U6.14 (OUT9)
unnamed: AFF6.18 (b), U6.13 (OUT8)
unnamed: AFF7.1 (a), U7.12 (OUT7)
unnamed: AFF7.2 (m), U7.11 (OUT6)
unnamed: AFF7.3 (k), U7.10 (OUT5)
unnamed: AFF7.4 (h), U7.9 (OUT4)
unnamed: AFF7.5 (u), U7.8 (OUT3)
unnamed: AFF7.6 (s), U7.7 (OUT2)
unnamed: AFF7.7 (t), U7.6 (OUT1)
unnamed: AFF7.8 (g), U7.5 (OUT0)
unnamed: AFF7.9 (f), U7.19 (OUT14)
unnamed: AFF7.10 (e), U7.20 (OUT15)
unnamed: AFF7.12 (DP), U9.6 (OUT1)
unnamed: AFF7.13 (d), U7.18 (OUT13)
unnamed: AFF7.14 (r), U7.17 (OUT12)
unnamed: AFF7.15 (p), U7.16 (OUT11)
unnamed: AFF7.16 (c), U7.15 (OUT10)
unnamed: AFF7.17 (n), U7.14 (OUT9)
unnamed: AFF7.18 (b), U7.13 (OUT8)
unnamed: AFF8.1 (a), U8.12 (OUT7)
unnamed: AFF8.2 (m), U8.11 (OUT6)
unnamed: AFF8.3 (k), U8.10 (OUT5)
unnamed: AFF8.4 (h), U8.9 (OUT4)
unnamed: AFF8.5 (u), U8.8 (OUT3)
unnamed: AFF8.6 (s), U8.7 (OUT2)
unnamed: AFF8.7 (t), U8.6 (OUT1)
unnamed: AFF8.8 (g), U8.5 (OUT0)
unnamed: AFF8.9 (f), U8.19 (OUT14)
unnamed: AFF8.10 (e), U8.20 (OUT15)
unnamed: AFF8.12 (DP), U9.5 (OUT0)
unnamed: AFF8.13 (d), U8.18 (OUT13)
unnamed: AFF8.14 (r), U8.17 (OUT12)
unnamed: AFF8.15 (p), U8.16 (OUT11)
unnamed: AFF8.16 (c), U8.15 (OUT10)
unnamed: AFF8.17 (n), U8.14 (OUT9)
unnamed: AFF8.18 (b), U8.13 (OUT8)
unnamed: D1.1 (K), U9.13 (OUT8)
unnamed: D2.1 (K), U9.14 (OUT9)
unnamed: D3.1 (K), U9.15 (OUT10)
unnamed: D4.1 (K), U9.16 (OUT11)
unnamed: D5.1 (K), U9.17 (OUT12)
unnamed: D6.1 (K), U9.18 (OUT13)
unnamed: D7.1 (K), U9.19 (OUT14)
unnamed: D8.1 (K), U9.20 (OUT15)
unnamed: F20.2, U20.2 (VIN)
unnamed: F21.2, U21.2 (VIN)
unnamed: JP1.2, U20.1 (OnOff)
unnamed: JP2.1, U20.5 (VOUT)
unnamed: JP3.2, U21.1 (OnOff)
unnamed: JP4.1, U21.5 (VOUT)
unnamed: P5.11, SW1.2
unnamed: R1.2, U1.23 (R-EXT)
unnamed: R2.2, U2.23 (R-EXT)
unnamed: R3.2, U3.23 (R-EXT)
unnamed: R4.2, U4.23 (R-EXT)
unnamed: R5.2, U5.23 (R-EXT)
unnamed: R6.2, U6.23 (R-EXT)
unnamed: R7.2, U7.23 (R-EXT)
unnamed: R8.2, U8.23 (R-EXT)
unnamed: R9.2, U9.23 (R-EXT)
unnamed: R20.1, R21.1
unnamed: R20.2, U20.4 (Trim)
unnamed: R22.1, R23.1
unnamed: R22.2, U21.4 (Trim)
VCC: C1.1, C2.1, C3.1, C4.1, C5.1, C6.1, C7.1, C8.1, C9.1, C30.1, C31.1, F30.2, JP4.2, P6.1, P9.1, U1.24 (VDD), U2.24 (VDD), U3.24 (VDD), U4.24 (VDD), U5.24 (VDD), U6.24 (VDD), U7.24 (VDD), U8.24 (VDD), U9.24 (VDD), U30.14 (VCC), U31.14 (VCC), W3.1
VIN: CON_PWR1.1, F20.1, F21.1, JP1.3, JP3.3, P7.1, P10.1, W2.1

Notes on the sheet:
RPi Interface
Note: 6A Capable Trace between VIN_I/O, GND_I/O and CON_PWR
POWER
Note: One the first of the multiple Display-Boards, the RPi-Section is populated, while on the other boards it can simply be left Blank. It contains an RPi Extension Port Socket, which connects the RPis SPI-Port via a Level-Shifter to the Shift-Registers and GPIO 22 to the LE Line of all Boards. It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
Note: On the first Board, CON_PWR and the 5V Power Module is populated. The 5V (VCC) generated here from is then passed on to the other boards, together with V_IN. V_LED is generated on each Board separately from V_IN. The Jumer on ONOFF are for positive/negative module selection. The Jumer on the 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
Voltage Testpoints
Note: The HCT-Type Gate here is used as a Level-Shifter from 3.3V to 5V, so it is important to use a HCT-Type Gate (not HC/AC/LS or other Type)
VCC
VLED
VIN
Note: The Rtrim resistor must be a 1/10 Watt precision metal film type, ±1% accuracy or better with low temperature coefficient, ±100 ppm/°C or better. Mount the resistor close to the converter.
GPIO 22
GPIO 18
GPIO 10
GPIO 11

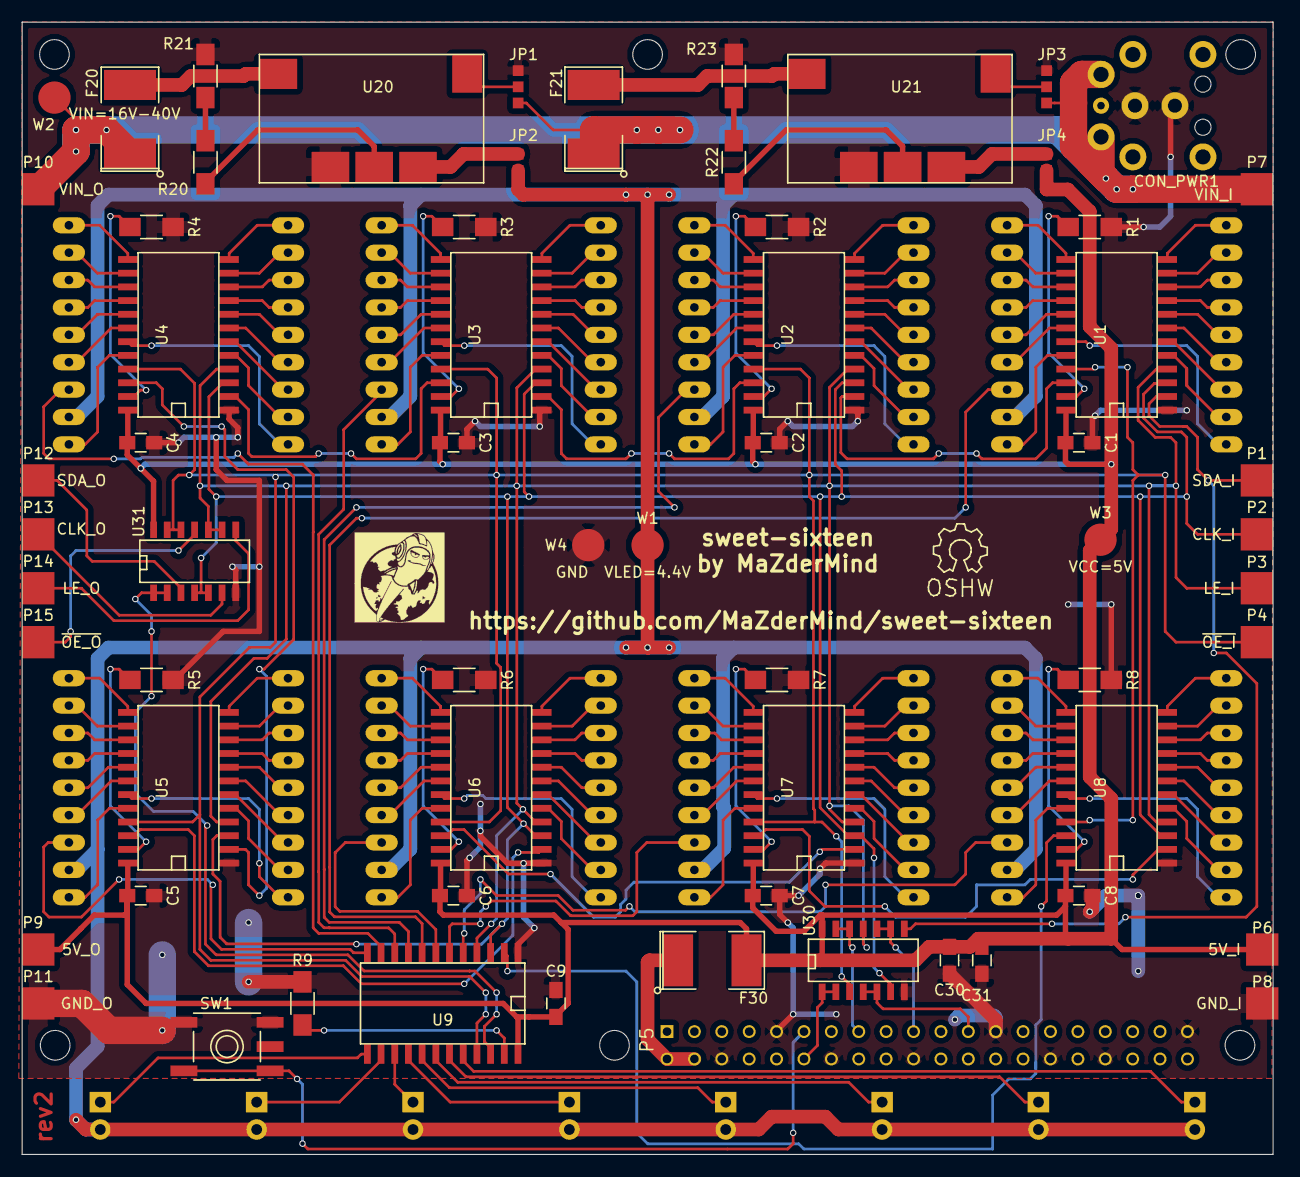
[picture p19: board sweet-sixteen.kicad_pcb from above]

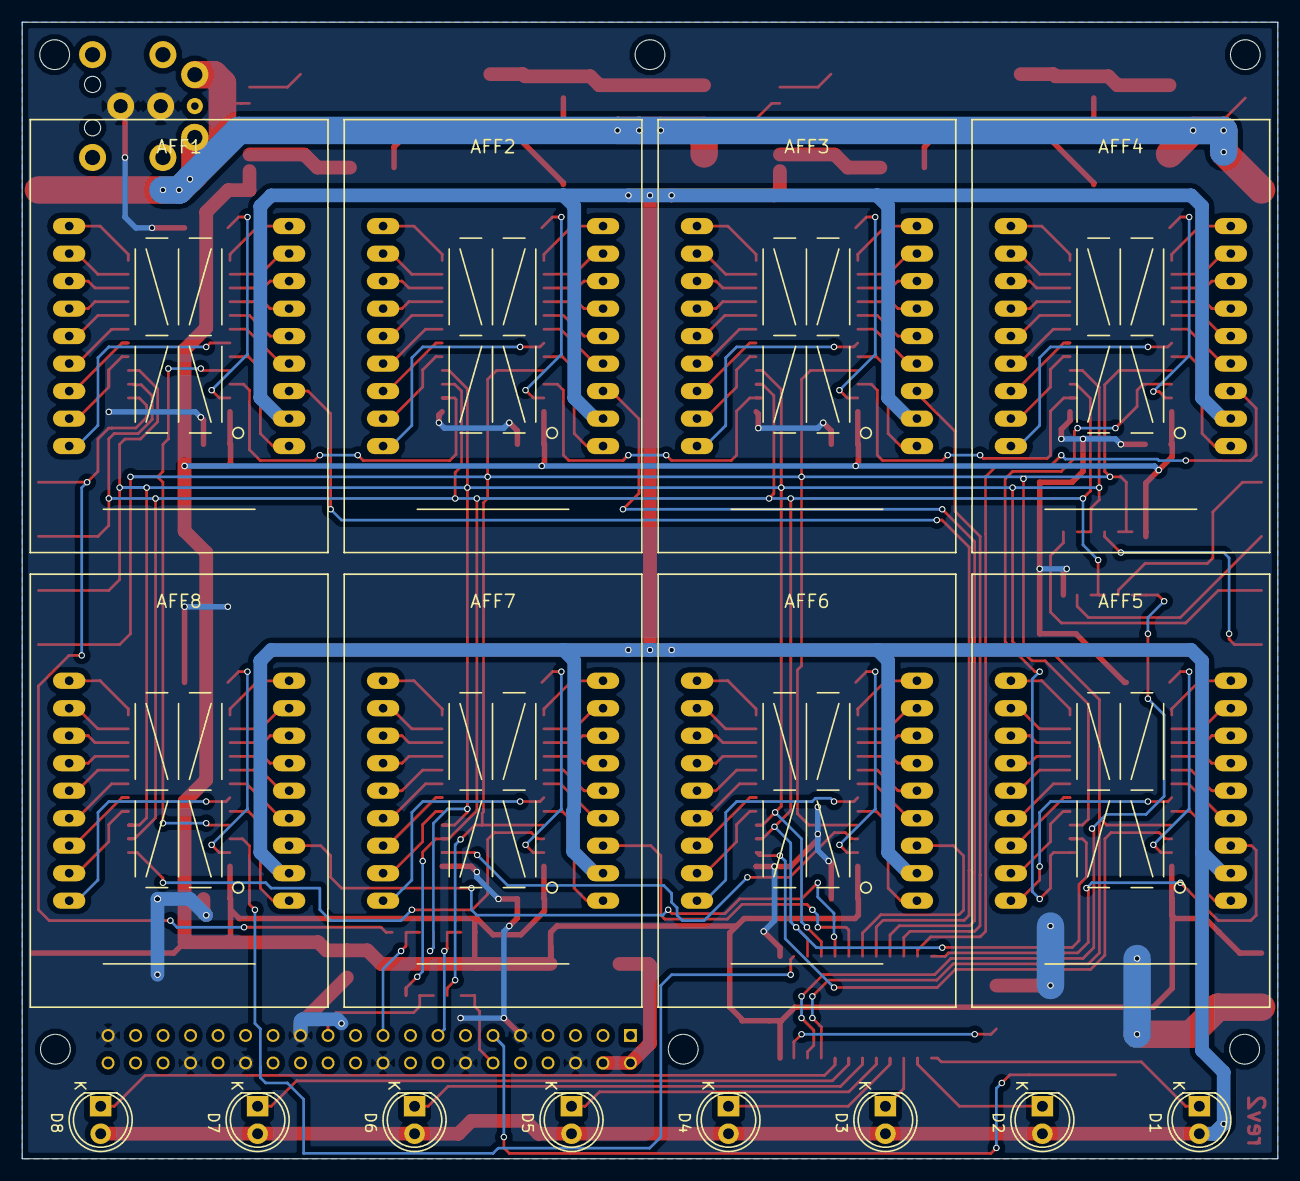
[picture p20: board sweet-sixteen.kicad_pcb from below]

Board: 2 copper layers, 116.0 x 105.0 mm, 81 parts (16 on the bottom side), 190 nets.

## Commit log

2016-12-10 empty project
    [sweet-sixteen.kicad_pcb, sweet-sixteen.sch]
2016-12-11 add datasheet for LED-DRiver
2016-12-11 add BOM csv
    [BOM.csv]
2016-12-11 place LED Modules
    [sweet-sixteen.sch]
2016-12-11 add led-drivers to schematic
    [sweet-sixteen.sch]
2016-12-11 wire up displays and driver
    [sweet-sixteen.sch]
2016-12-11 add power & gnd
    [sweet-sixteen.sch]
2016-12-11 restructute sch to be in line, add bus and i/o connector pads
    [sweet-sixteen.sch]
2016-12-11 add power in, pi note and pi interface
    [sweet-sixteen.sch]
2016-12-13 add level shifter, power net, 9th driver
    [sweet-sixteen.sch]
2016-12-13 make more use of unused space
    [sweet-sixteen.sch]
2016-12-13 make even more use out of that unused space
    [sweet-sixteen.sch]
2017-02-19 update docs
    [BOM.csv, BOM.ods, Power Calculations.ods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]
2017-02-19 remote control test-sw and updated power calc
    [Power Calculations.ods]
2017-02-19 redo schematic layout, pi interface, add output line driver, connect oe
    [sweet-sixteen.sch]
2017-02-19 redo power section, make erc pass
    [sweet-sixteen.sch]
2017-02-19 update bom, add 74hct08 datasheet
    [BOM.ods]
2017-02-19 update r value for trimming the vcc converter
    [sweet-sixteen.sch]
2017-02-19 setup footprints for jumper and assign known footprints
    [sweet-sixteen.sch]
2017-02-20 add note about Rtrim placement
    [sweet-sixteen.sch]
2017-02-20 move things around
    [BOM.ods, sweet-sixteen.sch]
2017-02-20 basic pcb placement
    [sweet-sixteen.kicad_pcb, sweet-sixteen.sch]
2017-02-20 flip displays correctly and fix silkscreen layer
    [sweet-sixteen.kicad_pcb]
2017-02-20 remove 3d model from solder-jumper
    [sweet-sixteen.kicad_pcb]
2017-02-21 (remove) mounting hole text, move mounting holes
    [sweet-sixteen.kicad_pcb]
2017-02-21 add more gnd-testpoints, move testpoint-labels to silkscreen
    [sweet-sixteen.kicad_pcb, sweet-sixteen.sch]
2017-02-21 move labels
    [sweet-sixteen.kicad_pcb]
2017-03-03 redo pcb, footprints, pi interface
    [sweet-sixteen.kicad_pcb, sweet-sixteen.sch]
2017-03-03 soldermask fixup
    [sweet-sixteen.kicad_pcb]
2017-03-03 move footprints to inch locations, fix outline, lock footprints
    [sweet-sixteen.kicad_pcb, sweet-sixteen.sch]
2017-03-03 power tracks and via stitching
    [sweet-sixteen.kicad_pcb]
2017-03-03 flip display 1-4 for bwtter routability
    [sweet-sixteen.kicad_pcb]
2017-03-03 digital bus
    [sweet-sixteen.kicad_pcb]
2017-03-03 VLED 50 mils
    [sweet-sixteen.kicad_pcb]
2017-03-03 More Power traces
    [sweet-sixteen.kicad_pcb, sweet-sixteen.sch]
2017-03-04 rework some parts of the power network on the way fo implement the digital bus
    [sweet-sixteen.kicad_pcb]
2017-03-04 finished digital and analog net, vled and vcc
    [sweet-sixteen.kicad_pcb]
2017-03-04 route put DP net
    [sweet-sixteen.kicad_pcb]
2017-03-04 all done but GND
    [sweet-sixteen.kicad_pcb, sweet-sixteen.sch]
2017-03-04 finished gnd routing
    [sweet-sixteen.kicad_pcb]
2017-03-04 symbols & markings
    [sweet-sixteen.kicad_pcb]
2017-03-04 move pcb on paper
    [sweet-sixteen.kicad_pcb]
2017-03-04 gerber files
    [sweet-sixteen-B.Cu.gbl, sweet-sixteen-B.SilkS.gbo, sweet-sixteen-Edge.Cuts.gm1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]
2017-03-04 after gerber generation
    [sweet-sixteen.kicad_pcb]
2017-03-04 fix pi-power routing
    [sweet-sixteen.kicad_pcb]
2017-03-05 add 3d models
    [sweet-sixteen.kicad_pcb]
2017-03-05 change footprint to fit reality - *doh*
2017-03-05 move chaining-pads to new outline, position pcb in a well described location on paper, fix outline to be on mm boundaries
    [sweet-sixteen.kicad_pcb]
2017-03-05 reposition everything, rip up everything… meeeh…
    [sweet-sixteen.kicad_pcb]
2017-03-05 re-route things with more care
    [sweet-sixteen.kicad_pcb, sweet-sixteen.sch]
2017-03-05 re-route all
    [sweet-sixteen.kicad_pcb, sweet-sixteen.sch]
2017-03-05 move hardware to folder
    [BOM.ods, Power Calculations.ods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]
2017-03-05 gerbers & drill-file
    [sweet-sixteen.kicad_pcb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]
2017-03-05 add chained image
2017-03-08 use relative paths for 3d models
    [sweet-sixteen.kicad_pcb]
2017-03-08 add extra vias on VIN
    [sweet-sixteen.kicad_pcb]
2017-03-08 remove wrong gnd pin on pi connecor, add some labels
    [sweet-sixteen.kicad_pcb, sweet-sixteen.sch]
2017-03-08 add 2.5M mounting holes to the top of the pcb
    [sweet-sixteen.kicad_pcb]
2017-03-11 clean up BOM, add Button
    [BOM.ods, sweet-sixteen.kicad_pcb, sweet-sixteen.sch]
2017-03-12 DELL Power Con
2017-03-19 place new connector footprint, update gerbers with soldermask
    [sweet-sixteen-B.Cu.gbl, sweet-sixteen-B.Mask.gbs, sweet-sixteen-B.SilkS.gbo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]
2017-05-12 Add fuses, make Parametric to number of Boards, Add Plugpack
    [BOM.ods]
2017-05-12 Remove Test-Sketches, will be replaced by RPi Driver-Software
2017-05-12 move files around to make them easier to find
    [sweet-sixteen-B.Cu.gbl, sweet-sixteen-B.Mask.gbs, sweet-sixteen-B.SilkS.gbo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]
2017-05-12 rev1 changes
    [sweet-sixteen.kicad_pcb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]
2017-05-12 add png/pdf version of schematic & pcb layout & link them from readme
